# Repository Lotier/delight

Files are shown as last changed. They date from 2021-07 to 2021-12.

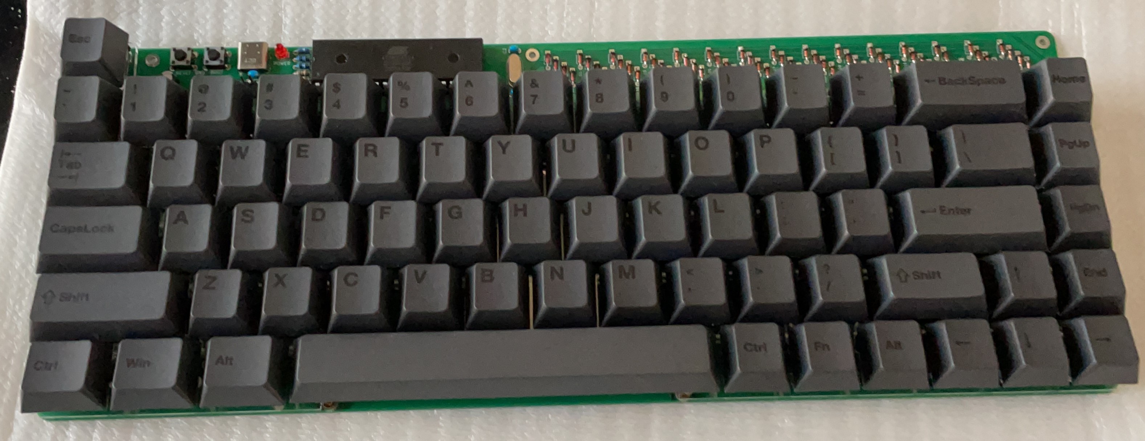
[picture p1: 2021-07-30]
doc/images/B188D2B5-2572-4F8E-8EDB-77D0E96EF30F.jpg

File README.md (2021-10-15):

# D-boards Keyboard

**65+% keyboard assembled with only through hole components, including usb type-c**
**65+% means there is an extra row at the top for the Escape key just for the delight of programmers.
DELIGHT is a multilayout board, supporting ANSI and ISO layouts with a few options for the bottom row.
DETACH is a hotswap ANSI board.

**[LICENSE](LICENSE)**

DELIGHT and DETACH are keyboards is licensed under the [Creative Commons Attribution-NonCommercial 4.0 International License](https://creativecommons.org/licenses/by-nc/4.0/). , this board is adapted from [coseyfannitutti Discipline](https://github.com/coseyfannitutti/discipline) work.

This PCB design may be freely reproduced, modified, and manufactured for **PERSONAL USE ONLY** and may not be reproduced in physical form for public sale.

If you have built upon this work and have changed the design in a significant way, the non-commercial clause can be waived. If you have developed your own design using files in this repository and would like to sell it, please contact me.

# Keyboard Layout Editor
http://www.keyboard-layout-editor.com/#/
```
[{a:7},"esc"],
["`","1","2","3","4","5","6","7","8","9","0","-","=",{w:2},"backspace","home"],
[{w:1.5},"tab","q","w","e","r","t","y","u","i","o","p","[","]",{w:1.5},"\\","pgup"],
[{w:1.75},"cap","a","s","d","f","g","h","j","k","l",";","'",{w:2.25},"enter","pgdn"],
[{w:2.25},"shift","z","x","c","v","b","n","m",",",".","/",{w:1.75},"shift","up","end"],
[{w:1.25},"ctrl",{w:1.25},"win",{w:1.25},"alt",{w:6.25},"","alt","fn","ctrl","left","down","right"]
```

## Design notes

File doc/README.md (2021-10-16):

# D-Boards Keyboards

[Build Guide \[To be updated\]]()

[VIA Configurator Guide (Easiest)\[To be updated\]]()

[QMK Toolbox Flashing Guide (not needed if using VIA)\[To be updated\]]()

[Command Line Flashing Guide (Advanced)\[To be updated\]]()

[Bootloader\[To be updated\]]()

[BOM (Parts List)](https://octopart.com/bom-tool/pwCbX6Qm)

- Upload Bootloader ROM to chip 
  - Bootloader sources differs so we use a atmega32a chip, but otherwises it's just a standard atmega32 chip
- Hit chip with fuse settings so its set to the 16mhz timing crystal.
  - Find exact command line arguement should be (`-U lfuse:w:0x7f:m -U hfuse:w:0xd9:m` or `-U lfuse:w:0x1f:m -U hfuse:w:0xc0:m`) I think
- Reboot chip
- In QMK Toolbox upload firmware.

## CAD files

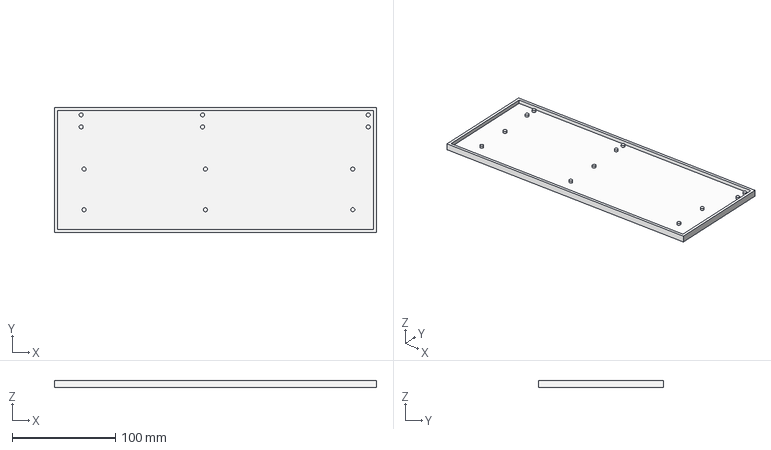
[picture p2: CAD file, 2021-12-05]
case/lowprofile/DelightCase.step
312.0 x 121.0 x 7.00 mm

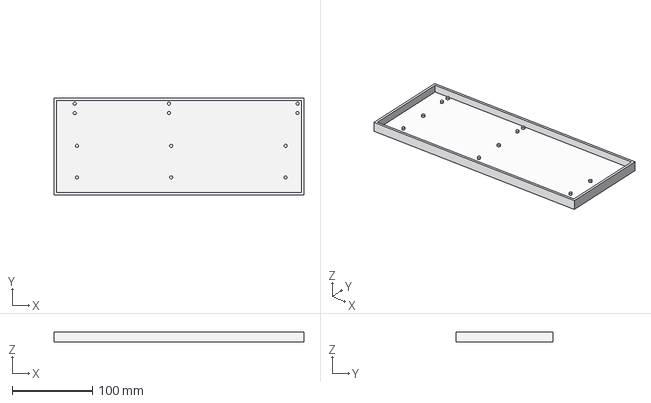
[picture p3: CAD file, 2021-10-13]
case/lowprofile/DelightCase-Body.step
312.0 x 121.0 x 12.5 mm

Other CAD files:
case/lowprofile/DelightCase.FCStd

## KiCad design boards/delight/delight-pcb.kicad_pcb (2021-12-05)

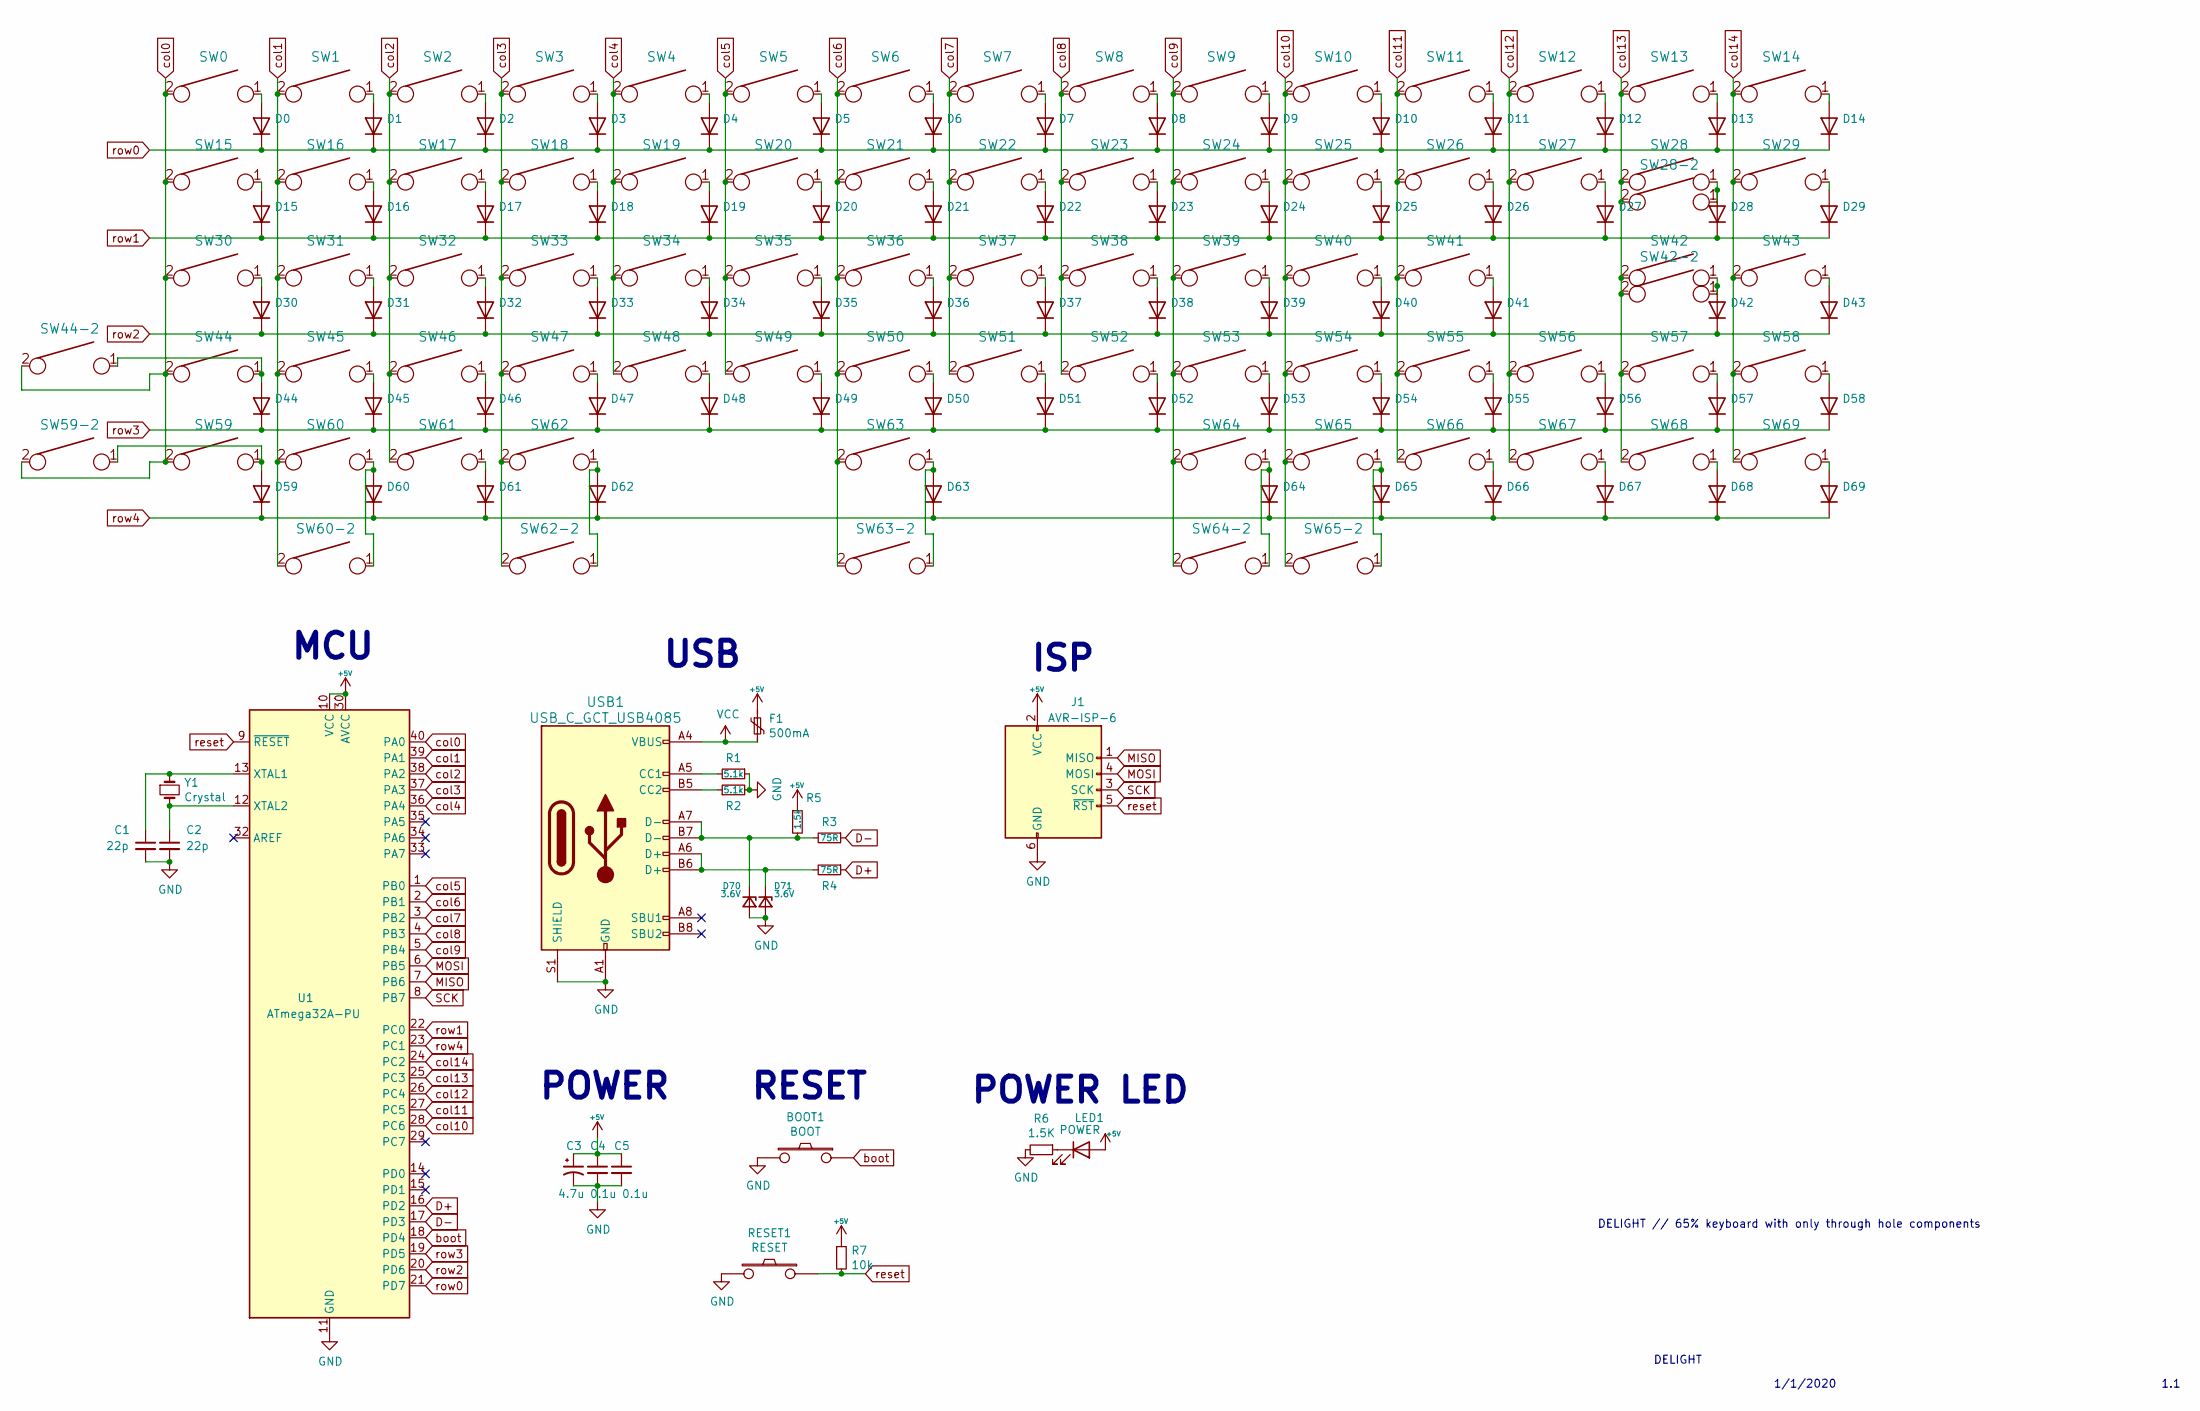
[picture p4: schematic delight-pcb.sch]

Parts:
BOOT1: BOOT; SW_PUSH_6mm
C1, C2: 22p; C_Disc_D3.0mm_W1.6mm_P2.50mm
C3: 4.7u; CP_Radial_D4.0mm_P1.50mm
C4, C5: 0.1u; C_Disc_D4.3mm_W1.9mm_P5.00mm
D0, D1, D2, D3, D4, D5, D6, D7, D8, D9, D10, D11, D12, D13, D14, D15, D16, D17, D18, D19, D20, D21, D22, D23, D24, D25, D26, D27, D28, D29, D30, D31, D32, D33, D34, D35, D36, D37, D38, D39, D40, D41, D42, D43, D44, D45, D46, D47, D48, D49, D50, D51, D52, D53, D54, D55, D56, D57, D58, D59, D60, D61, D62, D63, D64, D65, D66, D67, D68, D69: D_DO-35_SOD27_P7.62mm_Horizontal
D70, D71: 3.6V; D_DO-35_SOD27_P7.62mm_Horizontal
F1: 500mA; Fuse_Bourns_MF-RHT050
J1: AVR-ISP-6; PinHeader_2x03_P2.54mm_Vertical
LED1: POWER; LED_D3.0mm
R1, R2: 5.1k; R_Axial_DIN0204_L3.6mm_D1.6mm_P5.08mm_Horizontal
R3, R4: 75R; R_Axial_DIN0204_L3.6mm_D1.6mm_P5.08mm_Horizontal
R5: 1.5k; R_Axial_DIN0204_L3.6mm_D1.6mm_P5.08mm_Horizontal
R6: 1.5K; R_Axial_DIN0204_L3.6mm_D1.6mm_P5.08mm_Horizontal
R7: 10k; R_Axial_DIN0204_L3.6mm_D1.6mm_P5.08mm_Horizontal
RESET1: RESET; SW_PUSH_6mm
SW0, SW1, SW2, SW3, SW4, SW5, SW6, SW7, SW8, SW9, SW10, SW11, SW12, SW14, SW15, SW16, SW17, SW18, SW19, SW20, SW21, SW22, SW23, SW24, SW25, SW26, SW27, SW29, SW31, SW32, SW33, SW34, SW35, SW36, SW37, SW38, SW39, SW40, SW41, SW42-2, SW43, SW45, SW46, SW47, SW48, SW49, SW50, SW51, SW52, SW53, SW54, SW55, SW57, SW58, SW64, SW65, SW66, SW67, SW68, SW69: KEYSW; SW_Cherry_MX_PCB_1.00u
SW13: KEYSW; SW_Cherry_MX_PCB_2.00u
SW28, SW30, SW60-2, SW62-2, SW64-2, SW65-2: KEYSW; SW_Cherry_MX_PCB_1.50u
SW28-2: KEYSW; SW_Cherry_MX_Plate_ISOEnter
SW42, SW59: KEYSW; SW_Cherry_MX_PCB_2.25u
SW44, SW56: KEYSW; SW_Cherry_MX_PCB_1.75u
SW44-2, SW59-2, SW60, SW61, SW62: KEYSW; SW_Cherry_MX_PCB_1.25u
SW63: KEYSW; SW_Cherry_MX_PCB_6.25u
SW63-2: KEYSW; SW_Cherry_MX_PCB_7.00u
U1: ATmega32A-PU; DIP-40_W15.24mm
USB1: USB_C_GCT_USB4085; USB_C_Receptacle_GCT_USB4085
Y1: Crystal; Crystal_HC49-4H_Vertical

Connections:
+5V: C3.1, C4.1, C5.1, F1.1, J1.2 (VCC), LED1.2 (A), R5.1, R7.1, U1.10 (VCC), U1.30 (AVCC)
D+: R4.1, U1.16 (PD2)
D-: R3.1, U1.17 (PD3)
GND: BOOT1.2, C1.2, C2.2, C3.2, C4.2, C5.2, D70.2 (A), D71.2 (A), J1.6 (GND), R1.1, R2.2, R6.2, RESET1.2, U1.11 (GND), U1.31 (GND), USB1.A1 (GND), USB1.A12 (GND), USB1.B1 (GND), USB1.B12 (GND), USB1.S1 (SHIELD)
MISO: J1.1 (MISO), U1.7 (PB6)
MOSI: J1.4 (MOSI), U1.6 (PB5)
unnamed: C1.1, U1.13 (XTAL1), Y1.1
unnamed: C2.1, U1.12 (XTAL2), Y1.2
unnamed: D0.2 (A), SW0.1
unnamed: D1.2 (A), SW1.1
unnamed: D2.2 (A), SW2.1
unnamed: D3.2 (A), SW3.1
unnamed: D4.2 (A), SW4.1
unnamed: D5.2 (A), SW5.1
unnamed: D6.2 (A), SW6.1
unnamed: D7.2 (A), SW7.1
unnamed: D8.2 (A), SW8.1
unnamed: D9.2 (A), SW9.1
unnamed: D10.2 (A), SW10.1
unnamed: D11.2 (A), SW11.1
unnamed: D12.2 (A), SW12.1
unnamed: D13.2 (A), SW13.1
unnamed: D14.2 (A), SW14.1
unnamed: D15.2 (A), SW15.1
unnamed: D16.2 (A), SW16.1
unnamed: D17.2 (A), SW17.1
unnamed: D18.2 (A), SW18.1
unnamed: D19.2 (A), SW19.1
unnamed: D20.2 (A), SW20.1
unnamed: D21.2 (A), SW21.1
unnamed: D22.2 (A), SW22.1
unnamed: D23.2 (A), SW23.1
unnamed: D24.2 (A), SW24.1
unnamed: D25.2 (A), SW25.1
unnamed: D26.2 (A), SW26.1
unnamed: D27.2 (A), SW27.1
unnamed: D28.2 (A), SW28.1, SW28-2.1
unnamed: D29.2 (A), SW29.1
unnamed: D30.2 (A), SW30.1
unnamed: D31.2 (A), SW31.1
unnamed: D32.2 (A), SW32.1
unnamed: D33.2 (A), SW33.1
unnamed: D34.2 (A), SW34.1
unnamed: D35.2 (A), SW35.1
unnamed: D36.2 (A), SW36.1
unnamed: D37.2 (A), SW37.1
unnamed: D38.2 (A), SW38.1
unnamed: D39.2 (A), SW39.1
unnamed: D40.2 (A), SW40.1
unnamed: D41.2 (A), SW41.1
unnamed: D42.2 (A), SW42.1, SW42-2.1
unnamed: D43.2 (A), SW43.1
unnamed: D44.2 (A), SW44.1, SW44-2.1
unnamed: D45.2 (A), SW45.1
unnamed: D46.2 (A), SW46.1
unnamed: D47.2 (A), SW47.1
unnamed: D48.2 (A), SW48.1
unnamed: D49.2 (A), SW49.1
unnamed: D50.2 (A), SW50.1
unnamed: D51.2 (A), SW51.1
unnamed: D52.2 (A), SW52.1
unnamed: D53.2 (A), SW53.1
unnamed: D54.2 (A), SW54.1
unnamed: D55.2 (A), SW55.1
unnamed: D56.2 (A), SW56.1
unnamed: D57.2 (A), SW57.1
unnamed: D58.2 (A), SW58.1
unnamed: D59.2 (A), SW59.1, SW59-2.1
unnamed: D60.2 (A), SW60.1, SW60-2.1
unnamed: D61.2 (A), SW61.1
unnamed: D62.2 (A), SW62.1, SW62-2.1
unnamed: D63.2 (A), SW63.1, SW63-2.1
unnamed: D64.2 (A), SW64.1, SW64-2.1
unnamed: D65.2 (A), SW65.1, SW65-2.1
unnamed: D66.2 (A), SW66.1
unnamed: D67.2 (A), SW67.1
unnamed: D68.2 (A), SW68.1
unnamed: D69.2 (A), SW69.1
unnamed: D70.1 (K), R3.2, R5.2, USB1.A7 (D-), USB1.B7 (D-)
unnamed: D71.1 (K), R4.2, USB1.A6 (D+), USB1.B6 (D+)
unnamed: LED1.1 (K), R6.1
unnamed: R1.2, USB1.A5 (CC1)
unnamed: R2.1, USB1.B5 (CC2)
SCK: J1.3 (SCK), U1.8 (PB7)
VCC: F1.2, USB1.A4 (VBUS), USB1.A9 (VBUS), USB1.B4 (VBUS), USB1.B9 (VBUS)
boot: BOOT1.1, U1.18 (PD4)
col0: SW0.2, SW15.2, SW30.2, SW44.2, SW44-2.2, SW59.2, SW59-2.2, U1.40 (PA0)
col1: SW1.2, SW16.2, SW31.2, SW45.2, SW60.2, SW60-2.2, U1.39 (PA1)
col2: SW2.2, SW17.2, SW32.2, SW46.2, SW61.2, U1.38 (PA2)
col3: SW3.2, SW18.2, SW33.2, SW47.2, SW62.2, SW62-2.2, U1.37 (PA3)
col4: SW4.2, SW19.2, SW34.2, SW48.2, U1.36 (PA4)
col5: SW5.2, SW20.2, SW35.2, SW49.2, U1.1 (PB0)
col6: SW6.2, SW21.2, SW36.2, SW50.2, SW63.2, SW63-2.2, U1.2 (PB1)
col7: SW7.2, SW22.2, SW37.2, SW51.2, U1.3 (PB2)
col8: SW8.2, SW23.2, SW38.2, SW52.2, U1.4 (PB3)
col9: SW9.2, SW24.2, SW39.2, SW53.2, SW64.2, SW64-2.2, U1.5 (PB4)
col10: SW10.2, SW25.2, SW40.2, SW54.2, SW65.2, SW65-2.2, U1.28 (PC6)
col11: SW11.2, SW26.2, SW41.2, SW55.2, SW66.2, U1.27 (PC5)
col12: SW12.2, SW27.2, SW56.2, SW67.2, U1.26 (PC4)
col13: SW13.2, SW28.2, SW28-2.2, SW42.2, SW42-2.2, SW57.2, SW68.2, U1.25 (PC3)
col14: SW14.2, SW29.2, SW43.2, SW58.2, SW69.2, U1.24 (PC2)
reset: J1.5 (~RST), R7.2, RESET1.1, U1.9 (~RESET)
row0: D0.1 (K), D1.1 (K), D2.1 (K), D3.1 (K), D4.1 (K), D5.1 (K), D6.1 (K), D7.1 (K), D8.1 (K), D9.1 (K), D10.1 (K), D11.1 (K), D12.1 (K), D13.1 (K), D14.1 (K), U1.21 (PD7)
row1: D15.1 (K), D16.1 (K), D17.1 (K), D18.1 (K), D19.1 (K), D20.1 (K), D21.1 (K), D22.1 (K), D23.1 (K), D24.1 (K), D25.1 (K), D26.1 (K), D27.1 (K), D28.1 (K), D29.1 (K), U1.22 (PC0)
row2: D30.1 (K), D31.1 (K), D32.1 (K), D33.1 (K), D34.1 (K), D35.1 (K), D36.1 (K), D37.1 (K), D38.1 (K), D39.1 (K), D40.1 (K), D41.1 (K), D42.1 (K), D43.1 (K), U1.20 (PD6)
row3: D44.1 (K), D45.1 (K), D46.1 (K), D47.1 (K), D48.1 (K), D49.1 (K), D50.1 (K), D51.1 (K), D52.1 (K), D53.1 (K), D54.1 (K), D55.1 (K), D56.1 (K), D57.1 (K), D58.1 (K), U1.19 (PD5)
row4: D59.1 (K), D60.1 (K), D61.1 (K), D62.1 (K), D63.1 (K), D64.1 (K), D65.1 (K), D66.1 (K), D67.1 (K), D68.1 (K), D69.1 (K), U1.23 (PC1)

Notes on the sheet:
DELIGHT // 65% keyboard with only through hole components
1/1/2020
DELIGHT
1.1
MCU
USB
ISP
POWER
RESET
POWER LED

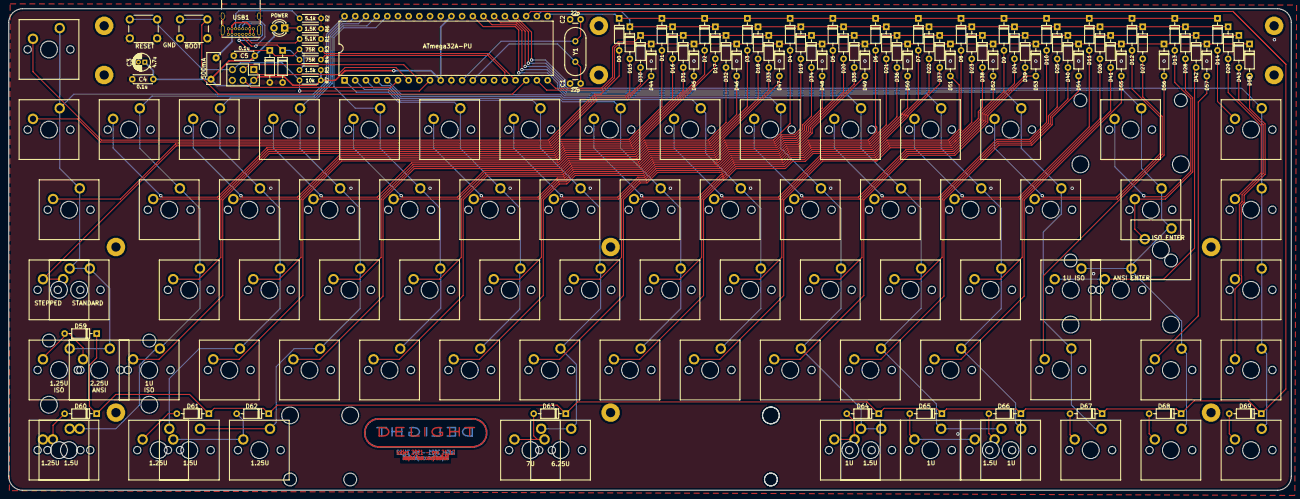
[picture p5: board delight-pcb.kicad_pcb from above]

Board: 2 copper layers, 304.9 x 114.5 mm, 176 parts (0 on the bottom side), 107 nets.

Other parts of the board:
ST13, ST42, ST59: Stabilizer_Cherry_MX_2u
ST63: 6.25U; Stabilizer_Cherry_MX_6.25u
ST63-2: 7U; Stabilizer_Cherry_MX_7u

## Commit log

2021-06-25 Base design of Delight Keyboard
    All traces are connected, it's not pretty, but it would work.
    [discipline-pcb.kicad_pcb, discipline-pcb.sch]
2021-06-26 Front Side Cleanup
    All major row/column wires are in a great spot now.
    [discipline-pcb.kicad_pcb]
2021-06-27 Last cleanup of placements.
    [discipline-pcb.kicad_pcb, discipline-pcb.sch]
2021-06-27 More trace design
    No more messing with it.
    [discipline-pcb.kicad_pcb]
2021-06-28 Wrapping Up
    Finished up all major tasks.
    [discipline-pcb.kicad_pcb, discipline-pcb.sch]
2021-07-01 Created Switch Plate
    [discipline-pcb.kicad_pcb, discipline-pcb.step, discipline-plate-base.dxf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]
2021-07-01 Cleanup of Files
    Just removing a bunch of the files.
    [acrylic-guard.dxf, discipline-bottom.dxf, discipline-closed-layer.dxf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]
2021-07-01 Attempted Project Rename
    Attempting to rename the project.
    [delight-pcb.kicad_pcb, delight-pcb.sch]
2021-07-01 Renaming Continued
    [delight-pcb.sch]
2021-07-01 Renaming Complete
    Finishing off all the renaming.
    [delight-pcb-B_Cu.gbl, delight-pcb-B_Mask.gbs, delight-pcb-Edge_Cuts.gm1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]
2021-08-11 Adding Low Profile Case Design
    [DelightCase-Body.step, DelightCase-Body2.step, DelightCase.FCStd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]
2021-08-11 Added Low Profile Plate Design
    * Fixup project structure.
    [delight-pcb-B_Cu.gbl, delight-pcb-B_Mask.gbs, delight-pcb-Edge_Cuts.gm1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]
2021-08-17 Adding components plate cover
2021-08-18 Start Process to design hotswap
    [delight-pcb.kicad_pcb]
2021-08-18 Add kicad library as submodules
2021-08-19 Startup For Using standard library
    [BOM.csv, DelightCase-Body.step, DelightCase-Body2.step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]
2021-08-27 Swapped out as many custom mods for standard.
    [Bourns_-_MF-R050.step, delight-pcb.kicad_pcb]
2021-08-27 Fixing the plate, since I can't do math.
2021-10-10 Cleanup of Plate Layout
2021-10-10 Cleaning up layout.
    [delight-pcb.kicad_pcb]
2021-10-10 Updated all routes.
    [delight-pcb.kicad_pcb, delight-pcb.sch]
2021-10-11 More cleanup
    [delight-pcb.kicad_pcb, delight-pcb.sch]
2021-10-11 Adding Stabs back in.
    [delight-pcb.kicad_pcb, delight-pcb.sch]
2021-10-11 Cleanup all the tracks after the footprint switch.
    [delight-pcb.kicad_pcb]
2021-10-12 Traces for power and pairs
    [delight-pcb.kicad_pcb]
2021-10-12 Footprint schema updated
    [delight-pcb.kicad_pcb, delight-pcb.sch]
2021-10-12 Once more with layouts
    [delight-pcb.kicad_pcb, delight-pcb.sch]
2021-10-12 mounting holes movement.
    [delight-pcb.kicad_pcb]
2021-10-12 More project cleanup
    [Bourns_-_MF-R050.step, delight-pcb.kicad_pcb, delight-pcb.sch]
2021-10-13 Final Cleanup
    [DelightCase-Body.step, DelightCase-Body2.step, DelightCase.FCStd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]
2021-10-14 Hotswap created and routed
    [delight-pcb-B_Cu.gbl, delight-pcb-B_Mask.gbs, delight-pcb-Edge_Cuts.gm1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]
2021-10-15 Reorg of project layout
    [delight-pcb-B_Cu.gbl, delight-pcb-B_Mask.gbs, delight-pcb-Edge_Cuts.gm1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]
2021-10-15 Detach - And project update (#2)
    * Add missing keyboard_parts.lib, fix symbol refs in schematic
    * Fix broken ref Y1 on pcb
    * Base design of Delight Keyboard
    * Front Side Cleanup
    * Last cleanup of placements.
    * More trace design
    * Wrapping Up
    * Remove ignored files
    * Created Switch Plate
    * Cleanup of Files
    * Attempted Project Rename
    * Renaming Continued
    * Renaming Complete
    Finishing off all the renaming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
    [BOM.csv, DelightCase-Body.step, DelightCase.FCStd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]
2021-10-15 Create a cherry stab only plate.
    Hopefully for better creation of the board that breaks less on the think parts.
2021-10-16 Add Octopart BOM to doc readme.
    [BOM.csv]
2021-10-17 Fixed up 3D reference for stabilizers
    [delight-pcb.kicad_pcb, detach.kicad_pcb]
2021-12-05 Updating the Low Profile Case
    [DelightCase.FCStd, DelightCase.step]
2021-12-05 Update Version Name
    [delight-pcb.kicad_pcb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]
2021-12-05 Drop the post .1 millimeter to match PCB thickness.
    [DelightCase.FCStd, DelightCase.step]
